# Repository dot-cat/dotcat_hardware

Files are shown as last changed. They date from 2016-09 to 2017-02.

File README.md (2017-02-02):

# .CAT hardware
Hardware designs for Creative Home Project and not only

## In this repo:
* sr_lights - PCB design of low-power LED driver module with serial interface (based on 8-bit shift register)
* sr_motors - PCB design of low-power motor driver module with serial interface (based on 8-bit shift register)
* sr_motors and sr_lights modules can be easily connected in series; but parrallel connection is recommended for power pins (to not overload input reverse polarity protection transistor)

## Notes:
For reverse polarity protection in cases of high load (more than 3 amps) try to replace an IRLML2244TRPbF transistor with AOD417. Example: https://learn.adafruit.com/16-channel-pwm-servo-driver/downloads

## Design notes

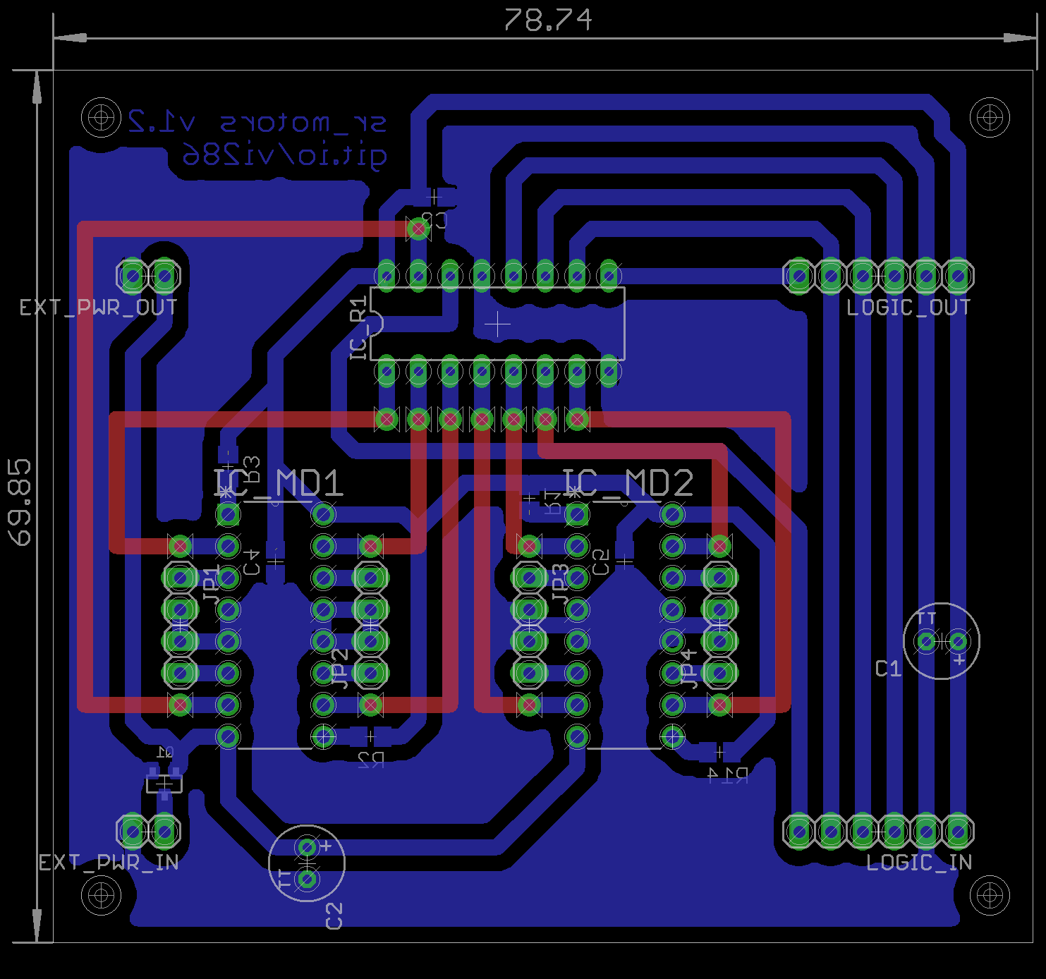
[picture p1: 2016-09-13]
sr_motors/sr_motors.brd.png

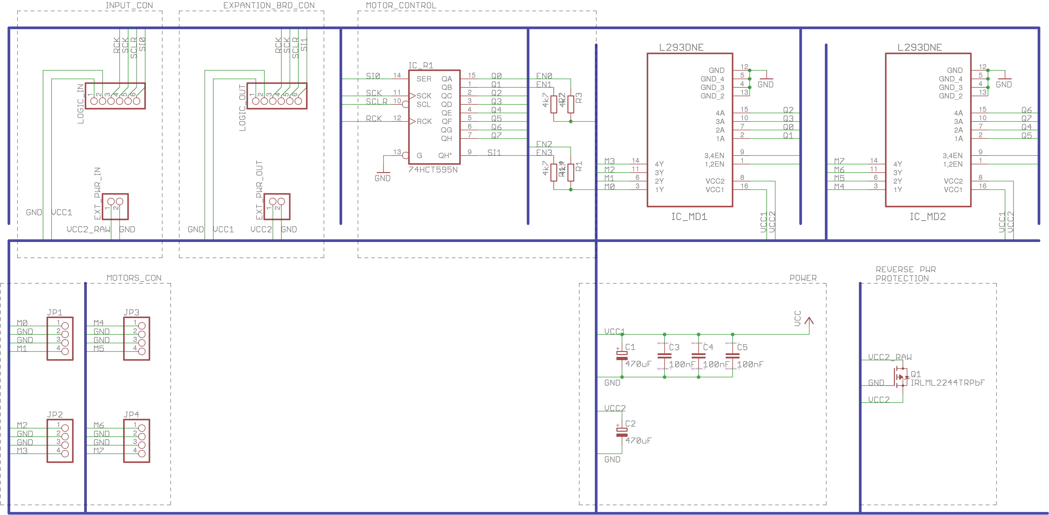
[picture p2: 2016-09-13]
sr_motors/sr_motors.sch.png

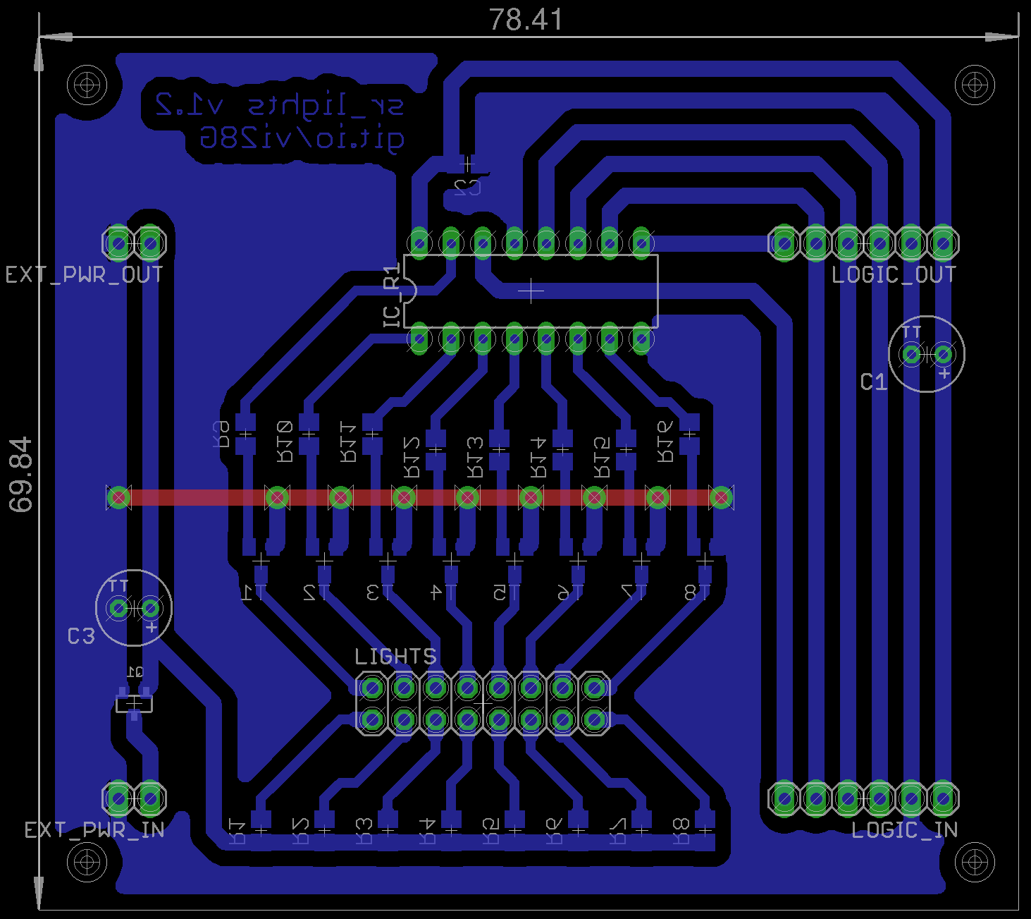
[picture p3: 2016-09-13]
sr_lights/sr_lights.brd.png

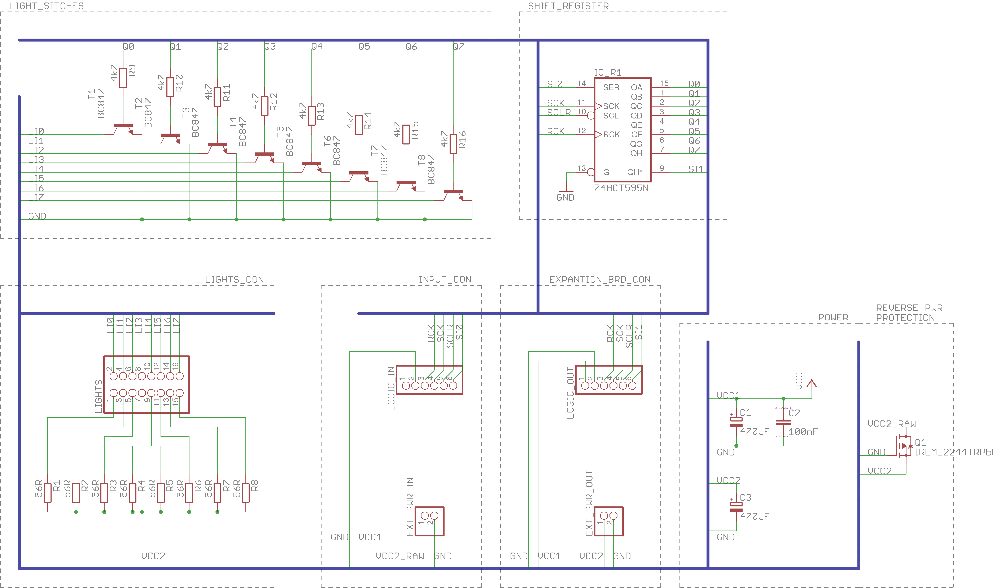
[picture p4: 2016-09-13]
sr_lights/sr_lights.sch.png

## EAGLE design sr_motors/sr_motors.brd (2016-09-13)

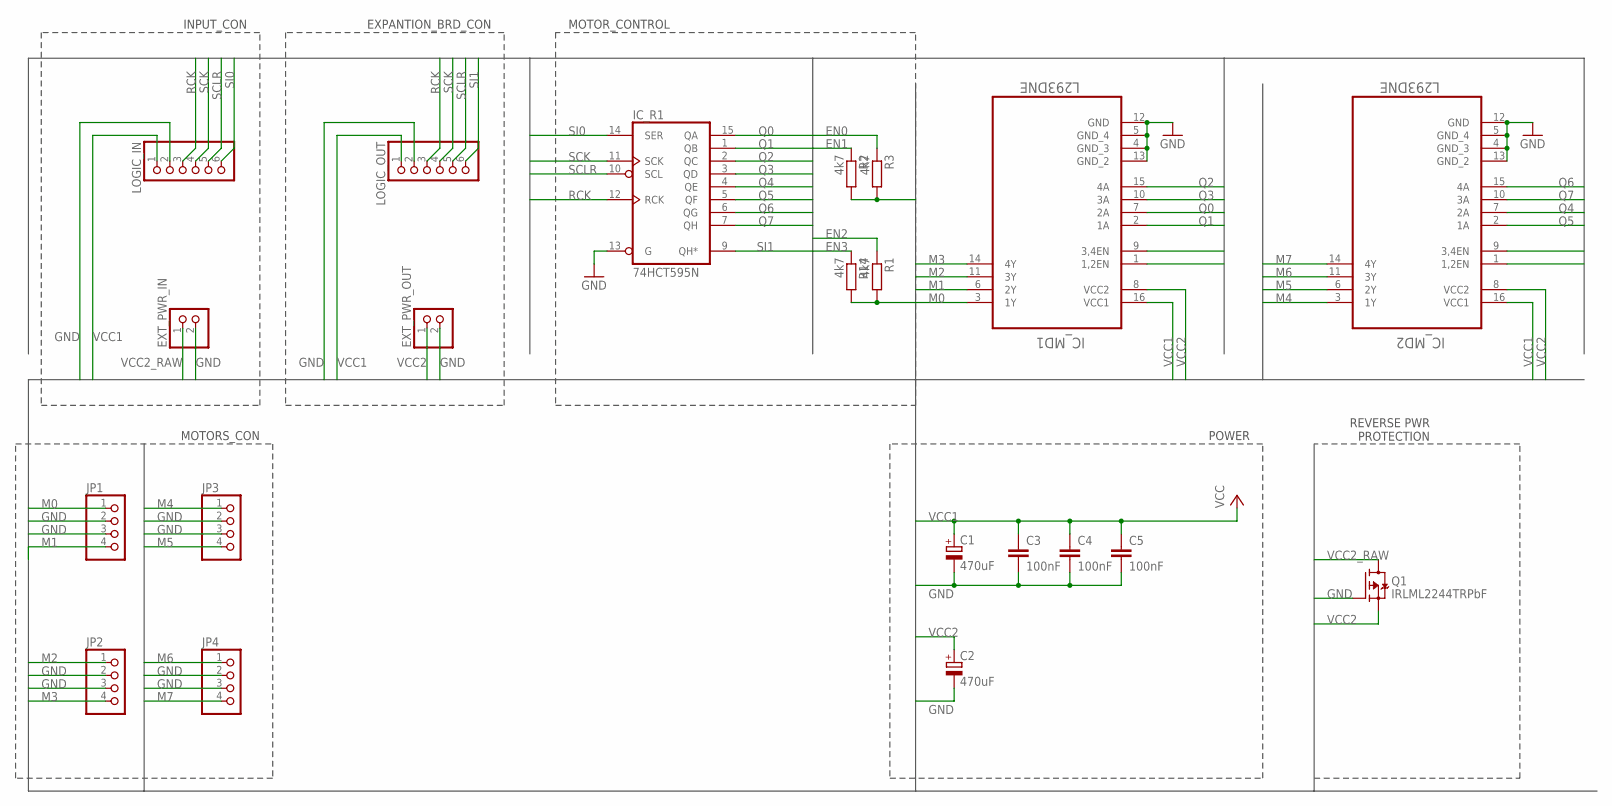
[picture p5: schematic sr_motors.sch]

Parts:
C1, C2: 470uF; TT2D6
C3, C4, C5: 100nF; C0805
EXT_PWR_IN: PINHD-1X2; 1X02
EXT_PWR_OUT: PINHD-1X2; 1X02
IC_MD1, IC_MD2: L293DNE; DIP254P762X508-16
IC_R1: 74HCT595N; DIL16
JP1, JP2, JP3, JP4: PINHD-1X4; 1X04
LOGIC_IN: PINHD-1X6; 1X06
LOGIC_OUT: PINHD-1X6; 1X06
Q1: IRLML2244TRPbF; SOT23
R1, R2, R3, R14: 4k7; M0805

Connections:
EN0: IC_MD1.1 (1,2EN), R3.1
EN1: IC_MD1.9 (3,4EN), R2.1
EN2: IC_MD2.1 (1,2EN), R1.1
EN3: IC_MD2.9 (3,4EN), R14.1
GND: C1.-, C2.-, C3.2, C4.2, C5.2, EXT_PWR_IN.2, EXT_PWR_OUT.2, IC_MD1.4 (GND_3), IC_MD1.5 (GND_4), IC_MD1.12 (GND), IC_MD1.13 (GND_2), IC_MD2.4 (GND_3), IC_MD2.5 (GND_4), IC_MD2.12 (GND), IC_MD2.13 (GND_2), IC_R1.8 (GND), IC_R1.13 (G), JP1.2, JP1.3, JP2.2, JP2.3, JP3.2, JP3.3, JP4.2, JP4.3, LOGIC_IN.2, LOGIC_OUT.2, Q1.1 (G)
M0: IC_MD1.3 (1Y), JP1.1
M1: IC_MD1.6 (2Y), JP1.4
M2: IC_MD1.11 (3Y), JP2.1
M3: IC_MD1.14 (4Y), JP2.4
M4: IC_MD2.3 (1Y), JP3.1
M5: IC_MD2.6 (2Y), JP3.4
M6: IC_MD2.11 (3Y), JP4.1
M7: IC_MD2.14 (4Y), JP4.4
Q0: IC_MD1.7 (2A), IC_R1.15 (QA)
Q1: IC_MD1.2 (1A), IC_R1.1 (QB)
Q2: IC_MD1.15 (4A), IC_R1.2 (QC)
Q3: IC_MD1.10 (3A), IC_R1.3 (QD)
Q4: IC_MD2.7 (2A), IC_R1.4 (QE)
Q5: IC_MD2.2 (1A), IC_R1.5 (QF)
Q6: IC_MD2.15 (4A), IC_R1.6 (QG)
Q7: IC_MD2.10 (3A), IC_R1.7 (QH)
RCK: IC_R1.12 (RCK), LOGIC_IN.3, LOGIC_OUT.3
SCK: IC_R1.11 (SCK), LOGIC_IN.4, LOGIC_OUT.4
SCLR: IC_R1.10 (SCL), LOGIC_IN.5, LOGIC_OUT.5
SI0: IC_R1.14 (SER), LOGIC_IN.6
SI1: IC_R1.9 (QH*), LOGIC_OUT.6
VCC1: C1.+, C3.1, C4.1, C5.1, IC_MD1.16 (VCC1), IC_MD2.16 (VCC1), IC_R1.16 (VCC), LOGIC_IN.1, LOGIC_OUT.1, R1.2, R2.2, R3.2, R14.2
VCC2: C2.+, EXT_PWR_OUT.1, IC_MD1.8 (VCC2), IC_MD2.8 (VCC2), Q1.2 (S)
VCC2_RAW: EXT_PWR_IN.1, Q1.3 (D)

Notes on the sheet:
POWER
EXPANTION_BRD_CON
INPUT_CON
MOTOR_CONTROL
MOTORS_CON
REVERSE PWR PROTECTION

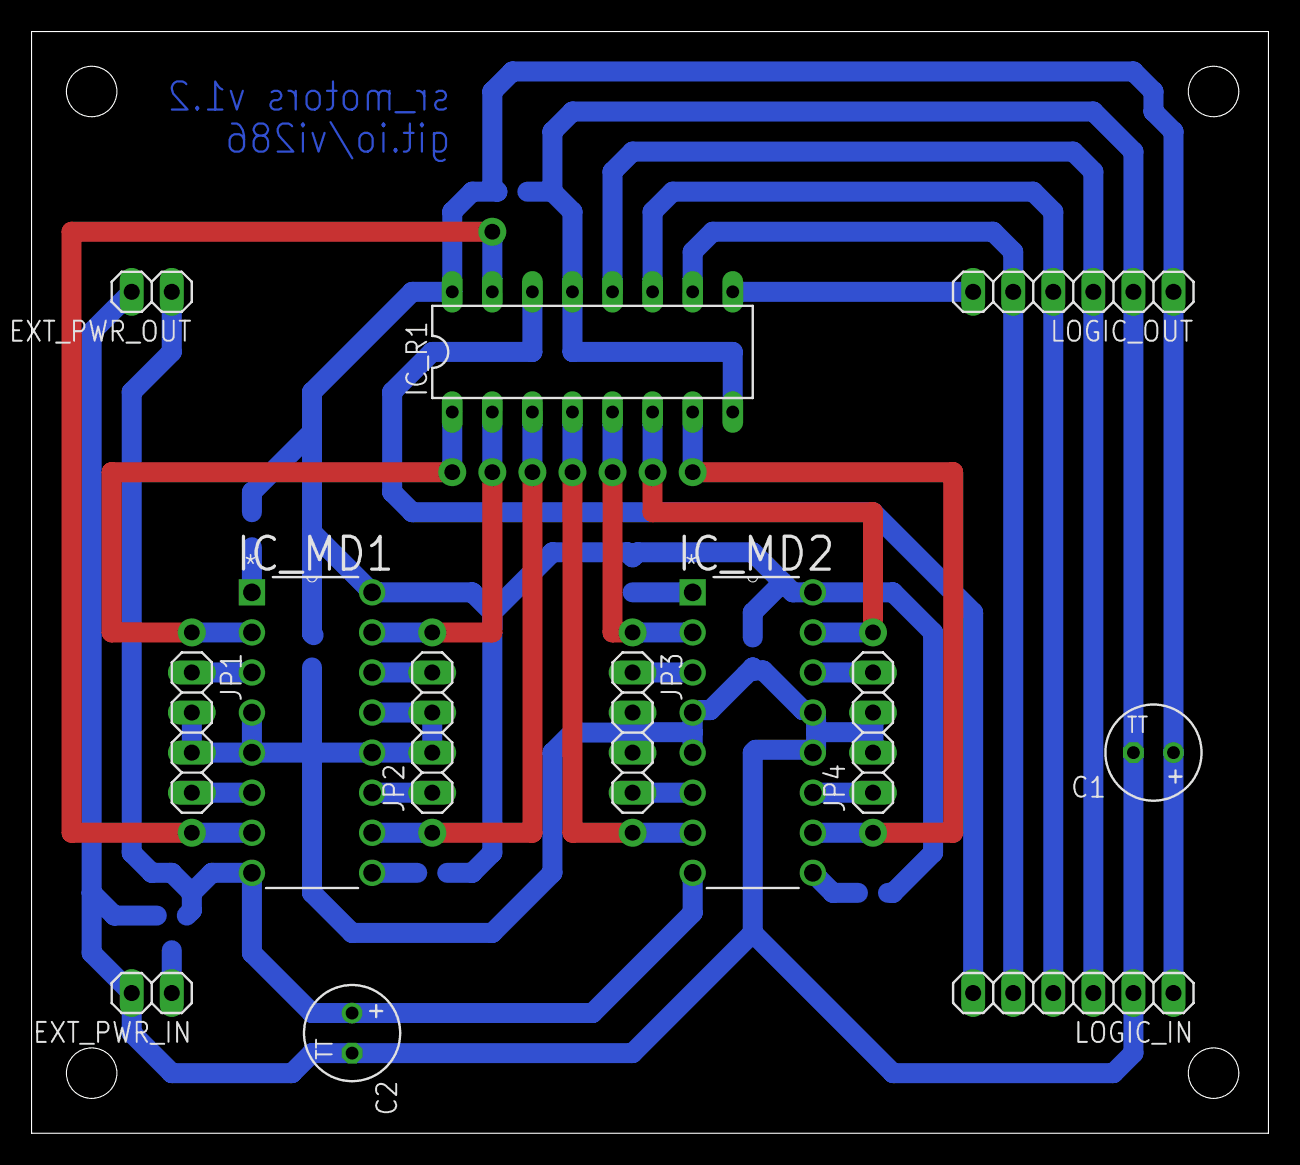
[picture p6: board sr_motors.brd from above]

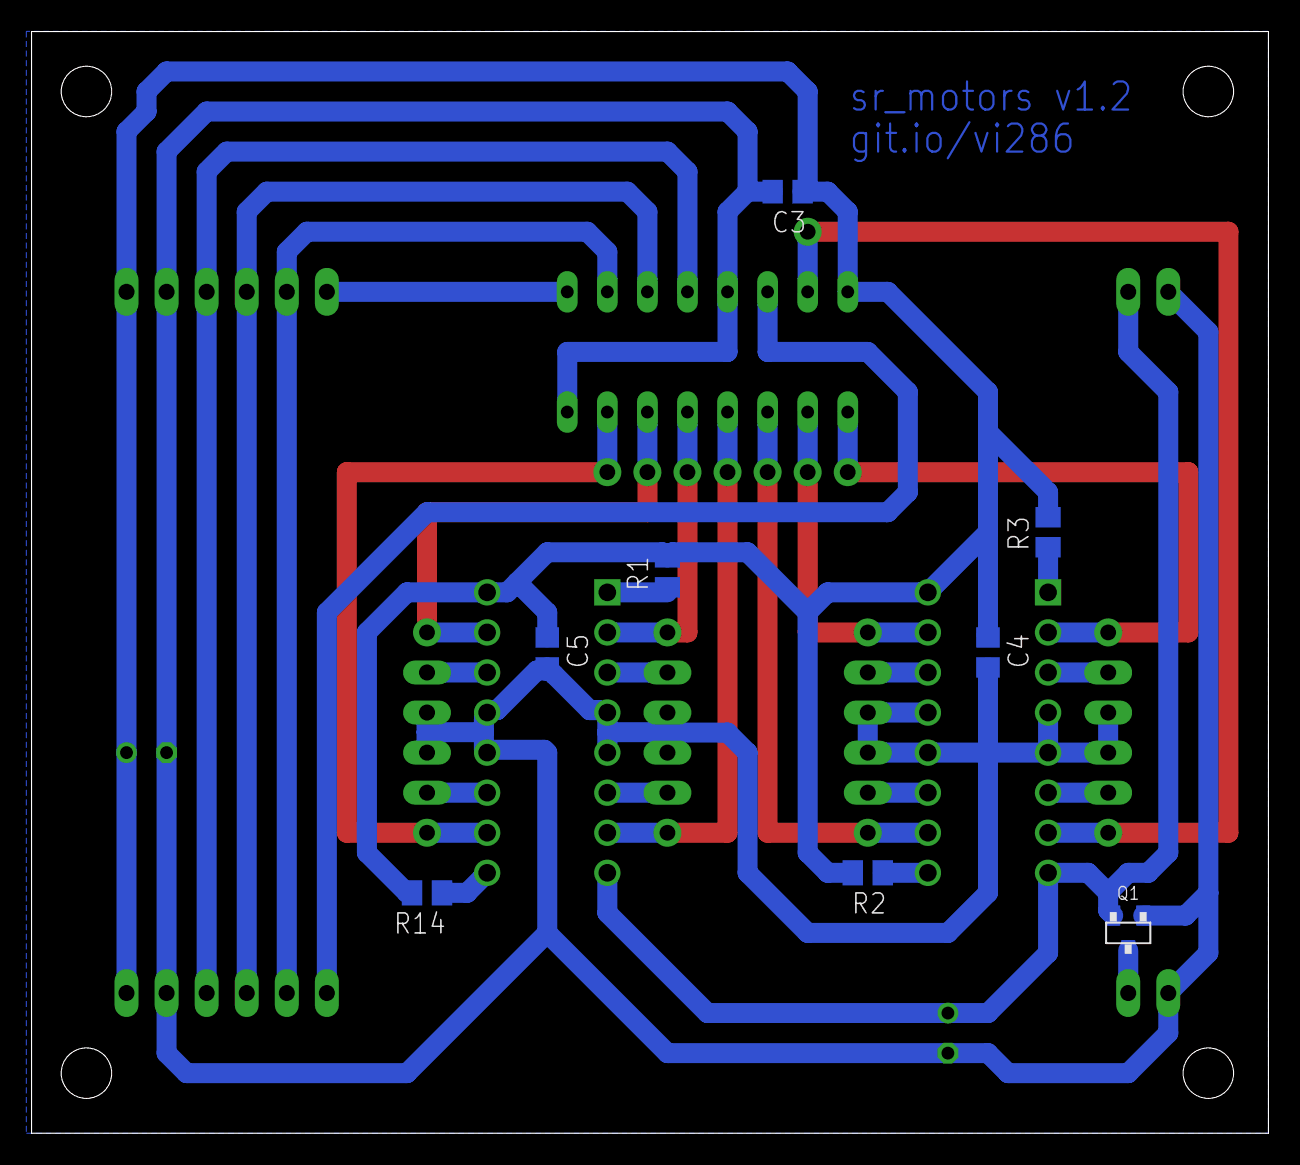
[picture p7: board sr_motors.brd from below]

Board: 2 copper layers, 78.4 x 69.8 mm, 21 parts (8 on the bottom side), 29 nets.

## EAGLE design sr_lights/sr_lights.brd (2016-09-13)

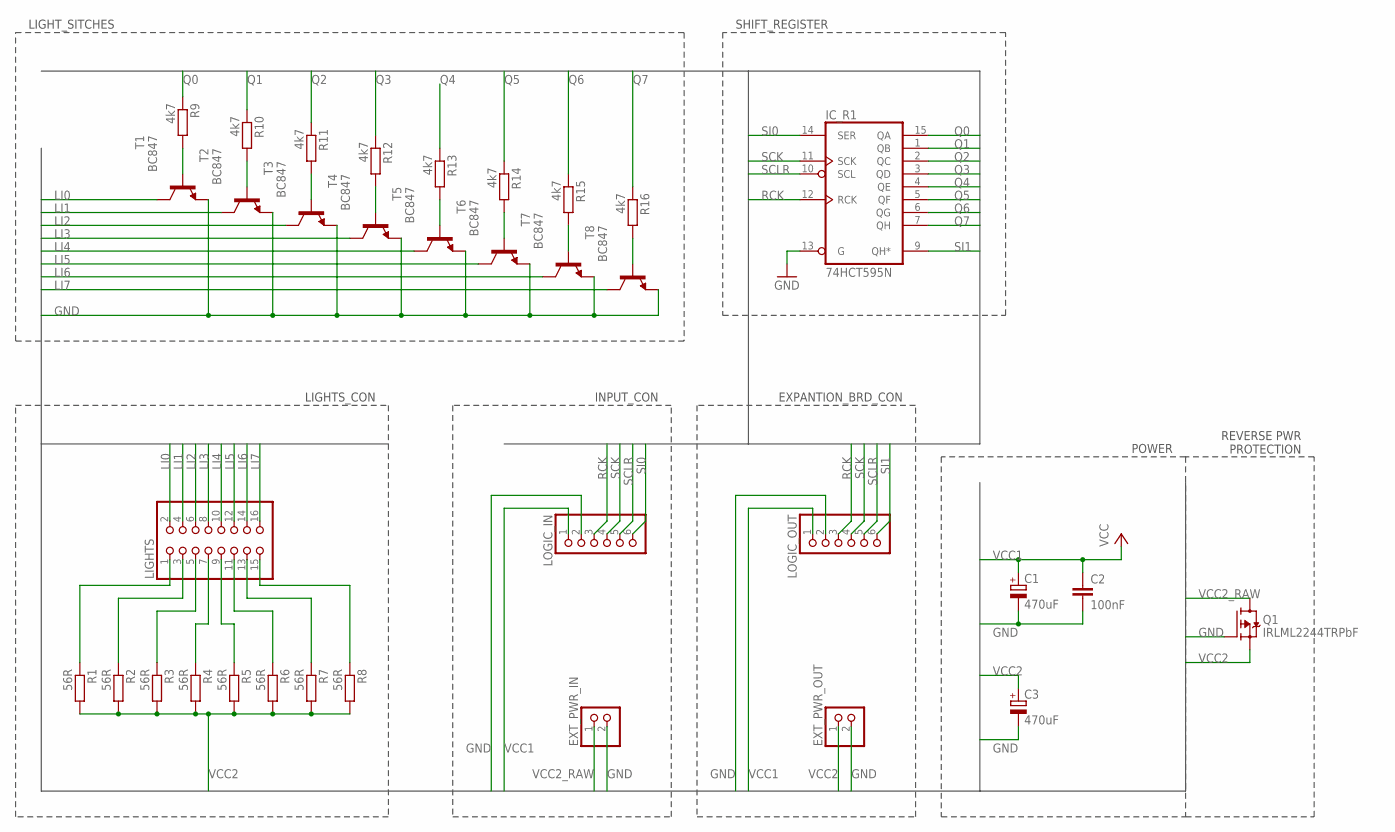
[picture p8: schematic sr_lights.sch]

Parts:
C1, C3: 470uF; TT2D6
C2: 100nF; C0805
EXT_PWR_IN: PINHD-1X2; 1X02
EXT_PWR_OUT: PINHD-1X2; 1X02
IC_R1: 74HCT595N; DIL16
LIGHTS: PINHD-2X8; 2X08
LOGIC_IN: PINHD-1X6; 1X06
LOGIC_OUT: PINHD-1X6; 1X06
Q1: IRLML2244TRPbF; SOT23
R1, R2, R3, R4, R5, R6, R7, R8: 56R; M0805
R9, R10, R11, R12, R13, R14, R15, R16: 4k7; M0805
T1, T2, T3, T4, T5, T6, T7, T8: BC847; SOT23

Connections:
GND: C1.-, C2.2, C3.-, EXT_PWR_IN.2, EXT_PWR_OUT.2, IC_R1.8 (GND), IC_R1.13 (G), LOGIC_IN.2, LOGIC_OUT.2, Q1.1 (G), T1.2 (E), T2.2 (E), T3.2 (E), T4.2 (E), T5.2 (E), T6.2 (E), T7.2 (E), T8.2 (E)
LI0: LIGHTS.2, T1.3 (C)
LI1: LIGHTS.4, T2.3 (C)
LI2: LIGHTS.6, T3.3 (C)
LI3: LIGHTS.8, T4.3 (C)
LI4: LIGHTS.10, T5.3 (C)
LI5: LIGHTS.12, T6.3 (C)
LI6: LIGHTS.14, T7.3 (C)
LI7: LIGHTS.16, T8.3 (C)
unnamed: LIGHTS.1, R1.1
unnamed: LIGHTS.3, R2.1
unnamed: LIGHTS.5, R3.1
unnamed: LIGHTS.15, R8.1
unnamed: LIGHTS.13, R7.1
unnamed: R9.2, T1.1 (B)
unnamed: R10.2, T2.1 (B)
unnamed: R11.2, T3.1 (B)
unnamed: R12.2, T4.1 (B)
unnamed: R13.2, T5.1 (B)
unnamed: R14.2, T6.1 (B)
unnamed: LIGHTS.11, R6.1
unnamed: LIGHTS.7, R4.1
unnamed: LIGHTS.9, R5.1
unnamed: R15.2, T7.1 (B)
unnamed: R16.2, T8.1 (B)
Q0: IC_R1.15 (QA), R9.1
Q1: IC_R1.1 (QB), R10.1
Q2: IC_R1.2 (QC), R11.1
Q3: IC_R1.3 (QD), R12.1
Q4: IC_R1.4 (QE), R13.1
Q5: IC_R1.5 (QF), R14.1
Q6: IC_R1.6 (QG), R15.1
Q7: IC_R1.7 (QH), R16.1
RCK: IC_R1.12 (RCK), LOGIC_IN.3, LOGIC_OUT.3
SCK: IC_R1.11 (SCK), LOGIC_IN.4, LOGIC_OUT.4
SCLR: IC_R1.10 (SCL), LOGIC_IN.5, LOGIC_OUT.5
SI0: IC_R1.14 (SER), LOGIC_IN.6
SI1: IC_R1.9 (QH*), LOGIC_OUT.6
VCC1: C1.+, C2.1, IC_R1.16 (VCC), LOGIC_IN.1, LOGIC_OUT.1
VCC2: C3.+, EXT_PWR_OUT.1, Q1.2 (S), R1.2, R2.2, R3.2, R4.2, R5.2, R6.2, R7.2, R8.2
VCC2_RAW: EXT_PWR_IN.1, Q1.3 (D)

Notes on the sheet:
POWER
EXPANTION_BRD_CON
INPUT_CON
SHIFT_REGISTER
LIGHT_SITCHES
LIGHTS_CON
REVERSE PWR PROTECTION

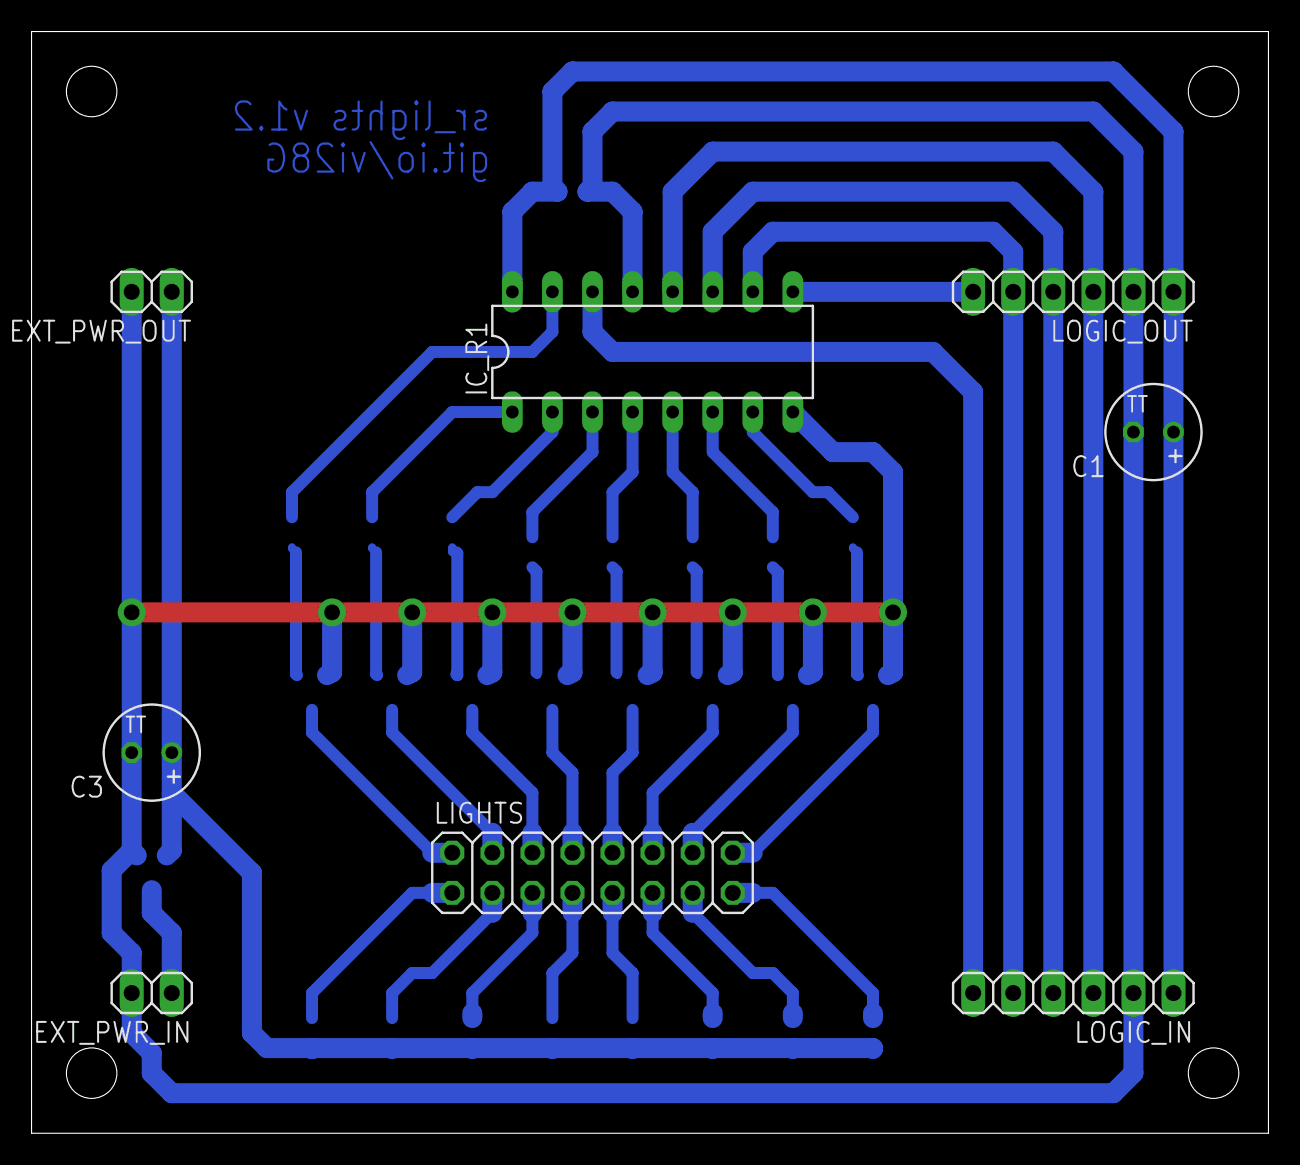
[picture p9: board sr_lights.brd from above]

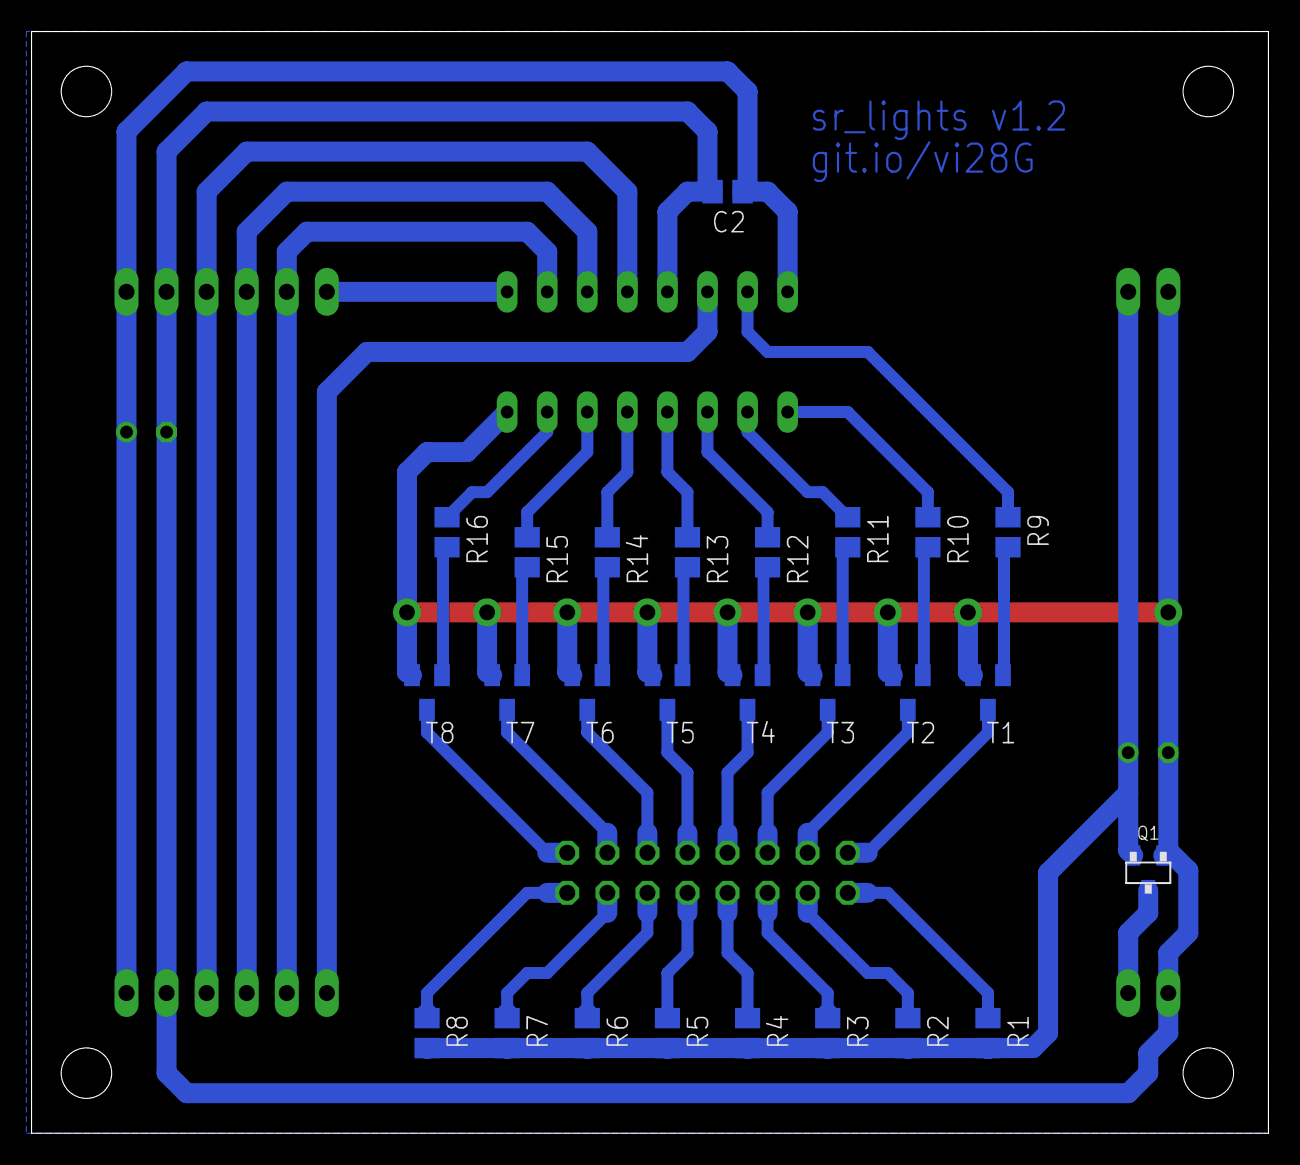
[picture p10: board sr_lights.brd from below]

Board: 2 copper layers, 78.4 x 69.8 mm, 34 parts (26 on the bottom side), 41 nets.

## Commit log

2016-08-13 Added sr_lights and sr_motors modules - versions on 03.08.16
    [sr_lights.brd, sr_lights.sch, sr_motors.brd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]
2016-08-13 Minor changes in sr_lights: DRC check, GND plane, moved some routes and components
    [sr_lights.brd, sr_lights.sch]
2016-08-13 DRC: Fixes and approves
    [sr_lights.brd]
2016-08-13 Routes and positions - aligned PWR connectors, top right hole - moved C3 capacitor - updated routes - approved some DRC errors (short route segments near pads)
    [sr_lights.brd]
2016-08-13 Added GND plane
    [sr_lights.brd]
2016-08-13 Route rework: - increased distance between wires - shifted capacitors, connectors and IC's - rerouted EN signals - other small changes
    [sr_motors.brd]
2016-08-15 Fixed Dimension layer
    [sr_lights.brd]
2016-08-15 Added design rules file
    [sr_motors.brd]
2016-08-15 DRC and align: Set the same DRC for lights and motors, fixed new DRC errors in sr_lights, aligned headers
    [sr_lights.brd, sr_motors.brd]
2016-09-13 Verion 1.2: Increased route width and board width, small other changes
    Squashed commit of the following:
    commit cb5b4ae53fc73325e271569d8207a4f4cb0d995e
    Author: Sergey Kostyuk <contact@s-kostyuk.me>
    Date: Tue Sep 13 19:34:33 2016 +0300
    Increaded width of routes, increased board width, replaced capacitor package, updated board version
    commit 30ef558f6f82cadcaf764826f9decc7df1a17ce0
    Author: Sergey Kostyuk <contact@s-kostyuk.me>
    Date: Tue Sep 13 19:27:19 2016 +0300
    Replaced capacitor package
    commit a2d398c50457a8d09da237926f830a1984b8064b
    Author: Sergey Kostyuk <contact@s-kostyuk.me>
    Date: Tue Sep 13 18:08:38 2016 +0300
    Icreased width of routes, icreased board width
    com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
    [sr_lights.brd, sr_lights.sch, sr_motors.brd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]
2016-09-13 Fixed route width in 'low_power' net class
    [sr_motors.brd, sr_motors.sch]
